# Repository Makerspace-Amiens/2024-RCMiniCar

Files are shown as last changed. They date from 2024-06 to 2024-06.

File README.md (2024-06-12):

---
layout: home
nav_order: 1
title: Accueil
---

# Bienvenue sur notre documentation du projet Voiture RC

Bienvenue dans la documentation du projet Voiture RC. Ce site a pour but de fournir toutes les informations nécessaires pour comprendre, utiliser et reproduire efficacement notre projet.

 Image Voiture RC

## À propos du Projet

<!--Décrivez ici en quelques lignes l'objectif et l'aperçu général de votre projet. Quel est son but ? À qui est-il destiné ? Quels problèmes cherche-t-il à résoudre ?-->

Le projet vise à concevoir une voiture radio télécommandée ainsi que son guide de production. L'objectif principal est de fournir aux étudiants de l'école un moyen accessible et ludique de comprendre les principes de base de l'ingénierie mécanique, électrique et de la télécommande sans fil. La conception compacte de la voiture permettra la création de circuits à taille humaine, favorisant ainsi des compétitions amusantes et éducatives entre les étudiants.

Ce projet résout plusieurs problèmes potentiels : il offre une opportunité d'apprentissage pratique, encourage la créativité et l'innovation. De plus, il permet de rendre l'apprentissage de concepts techniques plus attrayant en le contextualisant dans un cadre de jeu interactif. En fournissant un guide de production détaillé, le projet facilite également la réplication du processus de fabrication, permettant ainsi à un plus grand nombre d'étudiants de bénéficier de cette expérience enrichissante.

## Poster



## Vidéo

<video src="main/docs/images/videopres.mp4" controls title="Title" style="width: 100%;"></video>

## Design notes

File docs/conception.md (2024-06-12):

---
layout: default
nav_order: 7
title: Conception et prototypage
---

# Conception et prototypage
**Chassîs** 

Nous avons tout d’abord élaboré un plan sur papier pour estimer approximativement les tailles de nos composants ainsi que leurs emplacements. Après avoir eu une idée générale de la forme et des dimensions de notre châssis, Jules s'est chargé de le réaliser en 3D. Dans un premier temps, il a conçu un châssis très simple afin de tester les composants, commencer le câblage, le codage et vérifier le fonctionnement de la crémaillère.

Ensuite, nous avons développé un châssis plus opérationnel, avec des emplacements spécifiques pour chaque composant et des moyens de fixation adaptés. Pour ce faire, nous avons réalisé un assemblage sur SolidWorks, incluant tous les composants modélisés en 3D, afin d'obtenir les dimensions exactes de chaque élément. Cette étape nous a permis d’assurer une précision optimale dans la disposition et la fixation de chaque composant.

<script type="module" src="https://unpkg.com/@google/model-viewer/dist/model-viewer.min.js"></script>

<model-viewer id="viewer" alt="Modèle 3D du châssis" src="images/chassis3d.gltf" poster="images/Capture2.PNG" shadow-intensity="1" camera-controls touch-action="pan-y" style="width: 100%; height: 500px;">
</model-viewer>

**Crémaillère**
  
En ce qui concerne la crémaillère, nous avons d'abord effectué des recherches approfondies sur Internet pour comprendre les différents types de crémaillères utilisées dans les voitures réelles, le modélisme et les voitures radiocommandées. Ces informations nous ont permis de concevoir notre propre crémaillère sur SolidWorks.

Après avoir finalisé la conception, nous avons procédé à l'impression 3D de la crémaillère. Cependant, après plusieurs tentatives d'impression infructueuses, nous avons opté pour une impression en résine, beaucoup plus précise pour les petites pièces comme la nôtre. Cette technique nous a permis d'obtenir une crémaillère de haute qualité et adaptée à nos besoins spécifiques.

<model-viewer id="viewer" alt="Modèle 3D de la crémaillère" src="images/AssemblageCremaillere.gltf" poster="/docs/images/capture.jpg" shadow-intensity="1" camera-controls touch-action="pan-y" style="width: 100%; height: 500px;">
</model-viewer>

**Composants/Connectique**

Nous avons choisi divers composants pour réaliser cette voiture RC. Tout d'abord, nous avons fait des recherches pour déterminer quels moteurs étaient les plus propices à notre projet. Finalement, nous avons décidé de prendre des motoréducteurs moins encombrants et moins puissants. Ensuite, nous avons pris un ESP32 pour faire la relation entre les composants et nous permettre de le coder et de le contrôler soit par WiFi ou Bluetooth. D'autre part, pour faire la relation entre l'ESP32 et les motoréducteurs, nous avons pris un driver LN298 qui permet de contrôler les deux moteurs continus. Il peut faire tourner les moteurs à une vitesse continue ou en PWM. De plus, il inclut des diodes pour protéger le circuit, des résistances de rappel et un dissipateur de chaleur en cas de forte charge. Enfin, pour la direction de la voiture, nous avons pris un servo-moteur qui contribue à faire glisser la crémaillère de droite vers la gauche.
Pour la connectivité, nous avons utilisé des fils mâle/femelle et femelle/femelle pour connecter les différents composants entre eux. Cela assure une connexion fiable et flexible pour tous les éléments de la voiture RC.

<div style="display: flex; flex-wrap: wrap; gap: 10px; justify-content: space-between;">
  <model-viewer id="viewer1" alt="Modèle 3D des moteurs" src="images/moteur RC.gltf" poster="images/capture.jpg" shadow-intensity="1" camera-controls touch-action="pan-y" style="width: 22%; height: 200px;"></model-viewer>
  <model-viewer id="viewer2" alt="Modèle 3D du driver" src="images/Driver.gltf" poster="images/capture.jpg" shadow-intensity="1" camera-controls touch-action="pan-y" style="width: 22%; height: 200px;"></model-viewer>
  <model-viewer id="viewer3" alt="Modèle 3D de l'ESP32" src="images/ESP32.gltf" poster="images/capture.jpg" shadow-intensity="1" camera-controls touch-action="pan-y" style="width: 22%; height: 200px;"></model-viewer>
  <model-viewer id="viewer4" alt="Modèle 3D du servomoteur" src="images/Servo.gltf" poster="images/capture.jpg" shadow-intensity="1" camera-controls touch-action="pan-y" style="width: 22%; height: 200px;"></model-viewer>
</div>

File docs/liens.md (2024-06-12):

---
layout: default
title: Pièces STL
parent: Notice de Construction
nav_order: 2
---

# Liens des pièces

## Châssis

 - [Châssis](download/Chassis.STL)

## Composants

- [Driver](download/Driver.STL)
- [ESP32](download/ESP32.STL)
- [Moteur](download/moteurRC.STL)
- [Servomoteur](download/Servo.STL)

## Crémaillère

- [Axe droit Crémaillère](download/axedroit.STL)
- [Axe gauche Crémaillère](download/axegauche.STL)
- [Coude Crémaillère](download/coude.STL)
- [Engrenage Crémaillère](download/engrenage.STL)
- [Rampe crantée Crémaillère](download/Rampeengrenage.STL)

## Glissière

- [Glissière fixe](download/glissierefixe.STL)
- [Rail Glissière](download/railglissiere.STL)

## Roue

- [Roue arrière](download/rouearriere.STL)
- [Roue avant](download/roueavant.STL)
- [Pneu](download/contourroue.STL)

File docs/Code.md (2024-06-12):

---
layout: default
title: Code
parent: Notice de Construction
nav_order: 1
---

```
#include <DabbleESP32.h>
#include <ESP32Servo.h>

Servo myServo;

// Définir les broches de l'ESP32 connectées au module L298N
#define ENA 21  // Broche pour le PWM du moteur A
#define IN1 4  // Broche pour la direction du moteur A
#define IN2 5 // Broche pour la direction du moteur A
#define ENB 23  // Broche pour le PWM du moteur B
#define IN3 12  // Broche pour la direction du moteur B
#define IN4 13  // Broche pour la direction du moteur B

const int servoPin = 32;

// Angles pour le contrôle du servo
const int angleCentre = 133;  // Position centrale (neutre)
const int angleDroite = 180; 
const int angleGauche = 90;  
void setup() {
  // Initialiser les broches comme sorties
  pinMode(ENA, OUTPUT);
  pinMode(IN1, OUTPUT);
  pinMode(IN2, OUTPUT);
  pinMode(ENB, OUTPUT);
  pinMode(IN3, OUTPUT);
  pinMode(IN4, OUTPUT);
  
  // Initialiser la communication série pour le débogage
  Serial.begin(115200);
  myServo.attach(servoPin);
  
  // Mettre le servo en position neutre
  myServo.write(angleCentre);
  // Initialiser Dabble
  Dabble.begin("Nom_Bluetooth");  
  }

void loop() {

  Dabble.processInput();

  if (GamePad.isUpPressed()) {
    avancer();
  } else if (GamePad.isDownPressed()) {
    reculer();

  } else {
    arreter();
  }
  if (GamePad.isTrianglePressed()) {
    tournerDroite();
  } 
  
  // Vérifier si le bouton Y est pressé
  if (GamePad.isCirclePressed()	) {
    tournerGauche();
  }
  
  // Vérifier si aucun bouton n'est pressé
  if (!GamePad.isTrianglePressed() && !GamePad.isCirclePressed()) {
    arreterservo();
  }
}

void avancer() {
  // Avancer le moteur A
  digitalWrite(IN1, HIGH);
  digitalWrite(IN2, LOW);
  analogWrite(ENA, 155);  // Vitesse maximale pour le moteur A

  // Avancer le moteur B
  digitalWrite(IN3, HIGH);
  digitalWrite(IN4, LOW);
  analogWrite(ENB, 155);  // Vitesse maximale pour le moteur B

  Serial.println("Les moteurs avancent.");
}

void reculer() {
  // Reculer le moteur A
  digitalWrite(IN1, LOW);
  digitalWrite(IN2, HIGH);
  analogWrite(ENA, 155);  // Vitesse maximale pour le moteur A

  // Reculer le moteur B
  digitalWrite(IN3, LOW);
  digitalWrite(IN4, HIGH);
  analogWrite(ENB, 155);  // Vitesse maximale pour le moteur B

  Serial.println("Les moteurs reculent.");
}
void arreter() {
  // Arrêter le moteur A
  digitalWrite(IN1, LOW);
  digitalWrite(IN2, LOW);
  analogWrite(ENA, 0);  // Arrêter le moteur A

  // Arrêter le moteur B
  digitalWrite(IN3, LOW);
  digitalWrite(IN4, LOW);
  analogWrite(ENB, 0);  // Arrêter le moteur B

  Serial.println("Les moteurs sont arrêtés.");
}
void tournerDroite() {
  myServo.write(angleDroite);
  Serial.println("Tourner à droite");
}

// Fonction pour tourner à gauche
void tournerGauche() {
  myServo.write(angleGauche);
  Serial.println("Tourner à gauche");
}

// Fonction pour arrêter le servo (revenir au centre)
void arreterservo() {
  myServo.write(angleCentre);
  Serial.println("Arrêté (centre)");
}

```

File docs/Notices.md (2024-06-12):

---
layout: default
nav_order: 8
title: Notice de Construction 
has_children: true
---

# Notice de Construction de la Voiture RC

## 1. Préparation des Matériaux

### Matériaux nécessaires
Pour la réalisation de cette voiture RC, il vous faudra impérativement :

- Une imprimante 3D
- Des bobines de PLA et de TPU pour imprimer les pièces nécessaires
- Tournevis
- Fil de fer
- Rondelles
- Roulements
- Boulons
- Colle forte

## 2. Conception et Prototypage

#### Impression du châssis
La première étape consiste à imprimer le châssis qui permettra de poser et fixer les différents éléments de la voiture.

chassis

#### Impression de la crémaillère de direction
La deuxième étape consiste à imprimer les différents éléments de la crémaillère de direction.

- Une rampe crantée
- Un engrenage
- Deux coudes
- Deux axes de direction

Vous pouvez modifier les diamètres inttérieurs des des axes en fonction du diamètre exterieur de vos roulements.

<p align="center">
  rampe cr
  coude
  axe
  engrenage
</p>

#### Impression des roues
Pour finir, vous pouvez imprimer les roues, composées de deux parties : la jante en PLA et le pneu en TPU.

- Deux jantes pour l'arrière (pour les axes des moteurs)
- Deux jantes pour l'avant (pour les roulements de la crémaillère)

roue

## 3. Assemblage du Châssis et de la Crémaillère

### Assemblage de la crémaillère
1. Fixez les différents éléments de la crémaillère entre eux à l'aide de fil de fer.
2. Collez la rampe crantée au centre de la glissière (achetée ou imprimée).
3. Fixez la glissière sur le châssis à l'aide de boulons.
4. Fixez vos deux roulements sur les axes de la crémaillère.
5. Mettez les roues sur les roulements.

cremaillere

## 3. Placement des composants sur le Châssis 

### Montage des motoréducteurs
1. Placez les moteurs DC dans les supports prévus à cet effet sur le châssis.
2. Fixez les moteurs solidement pour éviter qu'ils ne bougent pendant le fonctionnement.

### Installation du module ESP32
1. Montez le module ESP32 sur le châssis.

### Installation du module L298N
1. Montez le module L298N sur le châssis.

### Installation du servo-moteur
1. Placez le servo-moteur sur son support créé sur le châssis.
2. Fixez l'écrou sur le palonnier et installez l'écrou sur la denture de la crémaillère.

voiture

## 5. Connectique entre les Composants

### Connexion du module L298N aux moteurs
Connectez les bornes de sortie du module L298N aux bornes des moteurs DC (OUT1 et OUT2 pour un moteur, OUT3 et OUT4 pour l'autre).

### Connexion du module ESP32 au module L298N
Connectez les pins IN1, IN2, IN3 et IN4 du module L298N aux GPIOs appropriés de l'ESP32.
Connectez les pins ENA et ENB du module L298N aux GPIOs de l'ESP32 pour contrôler la vitesse des moteurs.

### Connexion du servo-moteur
Connectez le servo-moteur à un autre GPIO de l'ESP32.
Connectez le fil de signal du servo au GPIO choisi, et les fils d'alimentation et de masse aux pins 3V3 et GND de l'ESP32.

### Alimentation
Connectez une source d'alimentation appropriée au module L298N pour alimenter les moteurs (Vs=7,5V).
Assurez-vous que l'ESP32 est alimenté correctement via le module L298N sur l'entrée (Vss=5V).

cablage

## 6. Programmation de l'ESP32 avec Dabble

### Programmation de l'ESP32
1. Téléchargez et installez l'IDE Arduino.
2. Installez les bibliothèques nécessaires pour l'ESP32 et Dabble.

### Téléversement du code
1. Connectez l'ESP32 à votre ordinateur via un câble USB.
2. Sélectionnez le bon port COM dans l'IDE Arduino et téléversez le code.

### Installation de Dabble
1. Téléchargez l'application Dabble sur votre smartphone depuis le Google Play Store ou l'App Store.
2. Suivez les instructions pour installer et configurer l'application.

## 7. Test et calibration
1. Allumez la voiture RC et ouvrez l'application Dabble.
2. Testez les contrôles pour vous assurer que les moteurs et le servo fonctionnent correctement.
3. Ajustez le code si nécessaire pour améliorer la réactivité et la précision des contrôles.

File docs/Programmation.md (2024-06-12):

---
layout: default
nav_order: 9
title: Programmation
has_children: true
---
# Programmation

 Pour la programmation, nous avons choisi de piloter la voiture RC sur notre smartphone, soit par WiFi, soit par Bluetooth. Nous avons fait des recherches poussées sur Internet et avons décidé d'utiliser l'interface Blynk pour le WiFi et l'interface Dabble pour le Bluetooth. Nous avons codé sur Arduino le code pour chaque interface, puis nous l'avons téléversé dans l'ESP32. Ainsi, nous pouvons contrôler l'ESP32 soit par WiFi avec Blynk, soit par Bluetooth avec Dabble sur notre smartphone.

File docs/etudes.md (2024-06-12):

---
layout: default
nav_order: 4
title: Études et choix techniques
---

# Études et choix techniques

## 1. Étude de différentes voitures RC

Nous avons étudié différents types de voitures RC DIY pour déterminer les caractéristiques souhaitées telles que la taille, le type (tout-terrain, course, drift, etc.), et la gamme de prix.

## 2. Conception et spécifications

La conception de la voiture RC est définie, incluant :

- **Châssis** : Forme, fonctionnalité, capacité a accueillir les differents composants.
- **Crémaillère** : Design, fonctionnalité.
- **Roue** : Fonctionnalité et capacité a se fixer sur les roulements et les axes des moteurs
- **Dimensions et échelle** : Nous avons choisi une longueur de 20 cm et une largeur de 10 cm en fonction de l'usage.
- **Matériaux** : Sélection des matériaux pour le châssis, batterie, moteur, driver, ESP32, servo-moteur, etc.

## 3. Système de propulsion

Le choix du système de propulsion comprend :

- **Moteurs électriques** : Plus courants, offrant différentes gammes de puissance et de performance.
- **Moteurs thermiques** : Pour les modèles plus spécialisés, offrant une expérience plus authentique mais requérant plus d'entretien.

Finalement, nous avons choisi deux motoréducteurs de 3V chacun avec une vitesse de rotation de 500 RPM, correspondant à notre couple et à une puissance suffisante pour atteindre 1,5 m/s.

## 4. Électronique et contrôle

L'électronique embarquée joue un rôle crucial dans la performance et les fonctionnalités de la voiture :

- **Récepteur et émetteur (carte ESP32)** : Pour la communication entre la voiture et la télécommande.
- **Servomoteurs** : Pour la direction de la voiture.
- **Driver L298n** : Pour faire la liasion entre l'ESP32 et les moteurs

## 5. Pneus et roues

Les pneus et les roues sont adaptés au type de surface (asphalte, terre, herbe), influençant fortement l'adhérence et la maniabilité. Nous avons choisi de concevoir nos propres roues 3D avec une adhérence conséquente pour une meilleure maniabilité.

## 6. Programmation

Le codage sur Arduino permet d'établir toutes les fonctions de paramétrage dans l'ESP32 et de contrôler notre voiture soit par WiFi, soit par Bluetooth, à partir de notre téléphone.

## 7. Prototypage et tests

La fabrication du prototype sera suivie de tests nécessaires pour valider la conception, la durabilité et les performances. Cela peut inclure des ajustements et des modifications durant le projet.

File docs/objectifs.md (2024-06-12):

---
layout: default
nav_order: 3
title: Objectifs du projet
---

# Introduction

L'innovation et la technologie continuent de s'améliorer, et nous allons vous présenter nos objectifs pour la réalisation d'une voiture télécommandée conçue de A à Z. Ce projet incarne des mois de recherche, de conception et de tests, motivés par une passion pour l'ingénierie et une volonté de réussir.

Dans les paragraphes suivants, nous allons détailler le contexte, les objectifs et le cahier des charges du projet.

## Contexte du Projet

Étant étudiants en 3ème année d'école d'ingénieur, nous devons réaliser un projet de 75 heures. Passionnés d'automobile, nous avons choisi le projet de création d'une voiture RC. Au cours de notre cursus, nous avons appris la mécanique, l'électronique et la programmation théorique. Ce projet réunit ces trois disciplines et nous donnera l'occasion de renforcer notre compréhension des principes mécaniques (transmissions, suspensions), nos pratiques dans les circuits électriques et les systèmes de contrôle, ainsi que nos compétences en programmation.

En plus de servir d'apprentissage, ce projet offrira également une expérience pratique de travail en équipe. Chaque membre apportera ses connaissances en modélisation 3D, électronique et programmation. Ensemble, nous concevrons une voiture RC fonctionnelle.

Ainsi, le projet de création d'une voiture RC représente une opportunité passionnante dans notre cursus d'ingénieur et nous permettra de renforcer nos compétences techniques et notre capacité à collaborer.

## Objectifs du Projet

- Apprentissage de la mécanique, de l'électronique et de la programmation d'une voiture RC.
- Conception 3D de la voiture RC.
- Choix des bons composants (batteries, moteur, suspension, etc.).
- Création d'une carte électronique entre le moteur et la carte ESP32.
- Avoir une voiture fonctionnelle.
- Piloter la voiture avec notre téléphone en Bluetooth.

## Cahier des Charges

-Concevoir une voiture RC fonctionnelle

-Petite/moyenne taille (+-Longueur de 20cm, largeur de 10cm)

-Choisir des composants adaptés aux attentes de la voiture :

-Petite/moyenne

-Légère

-Vitesse de 5 km/h

-Contrôlable à distance

-intégrer les composants au châssis

-piloter la voiture avec son smartphone

-Budget de 150 € pour le développement complet du projet

### 3. Spécifications Techniques

- **Conception et Dimensions :** Longueur de 20 cm, largeur de 10 cm, châssis en 3D.
- **Système de Propulsion :** 2 motoréducteurs de 3V, 500 RPM, vitesse de 1,5 m/s.
- **Contrôle et Communication :** Carte ESP32, application mobile via Bluetooth ou WiFi pour les réglages avancés sur smartphone. Utilisation d'un driver LN298.
- **Alimentation :** Batterie LiPo 7.4V 5000mAh, autonomie de 30 minutes, recharge rapide en 1 heure.
- **Direction :** Direction assistée électroniquement par un servo-moteur fesant bouger une crémaillère.

### 4. Critères de Conception

- **Personnalisation :** 
  - Création d'un châssis s'adaptant à tous les composants utilisés.
  - Élaboration d'une coque de protection de la voiture RC.
  - Programmation de l'ESP32 à partir d'Arduino pour contrôler la voiture via un téléphone.

### 5. Plan de Développement

- **Phases du Projet :** Conception, Développement du prototype, Tests.
- **Calendrier :** Début du projet en février 2024, fin en juin 2024.
- **Ressources :** Équipe de 3 étudiants ingénieurs, logiciels de CAO, internet, etc.
- **Budget :** Estimé à 150 € pour le développement complet du projet.

### 6. Tests et Validation

- **Protocole de Tests :** Tests de performance, tests de résistance (chocs, usure), tests d'usage (contrôle, programme).
- **Critères de Validation :** Obtenir une voiture fonctionnelle et pilotable.

### 7. Modifications

- **Rapport de Projet :** Analyse des performances, retour sur le projet, améliorations, défauts.

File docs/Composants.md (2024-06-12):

---
layout: default
nav_order: 6
title: Les Composants
---

# Composants

## Module L298N
<div style="text-align: center;">
  Module L298N
</div>
<div style="text-align: left;">
  Le module L298N est un pont en H double qui permet de contrôler deux moteurs à courant continu ou un moteur pas à pas.

  Les Caractéristiques Techniques du Module L298N sont: Au niveau de l'Alimentation, Nous avons une Tension d'alimentation (Vss) de 5V, une Tension d'alimentation du moteur (Vs) : 5V à 35V
  un Courant de sortie maximal par canal : 2A

  Pour le Contrôle des Moteurs, il y a deux canaux : 2 (peut contrôler 2 moteurs DC ou 1 moteur pas à pas)
  avec une Puissance de sortie totale : 25W

  Les Connexions et les Broches :
  Les Broches IN1, IN2, IN3, IN4 : Entrées de contrôle pour les deux moteurs
  Les Broches ENA, ENB : Broches d'activation pour les moteurs A et B (permettent le contrôle de la vitesse avec PWM)
  Les Broches OUT1, OUT2, OUT3, OUT4 : Sorties vers les moteurs
  Les Broches Vss et GND : Connexion à l'alimentation logique
  La Broche Vs : Connexion à l'alimentation des moteurs

  Les Fonctionnalités
  Il est capable de contrôler la direction et la vitesse de rotation des moteurs.
  Il permet d'utiliser des signaux PWM pour contrôler la vitesse des moteurs.
  Il peut être utilisé pour contrôler des moteurs à courant continu, des moteurs pas à pas bipolaires ou unipolaires.
</div>

## ESP32
<div style="text-align: center;">
  ESP32
</div>
<div style="text-align: left;">
  L'ESP32 est une série de microcontrôleurs. Nous l'avons choisi en raison de ses caractéristiques avancées et de sa polyvalence.

  Les Caractéristiques Principales

  Une Connectivité Sans Fil :

  Avec le Wi-Fi, il permet la connexion à des réseaux sans fil pour la communication et l'échange de données.
  Avec le Bluetooth et BLE (Bluetooth Low Energy) qui supporte les communications Bluetooth classiques et basse consommation, permettant une large gamme d'applications sans fil.

  De Nombreuses Interfaces de Communication :

  -GPIO : Plusieurs broches d'entrée/sortie générales.
  -ADC (Convertisseur Analogique-Numérique) : Permet de lire des signaux analogiques.
  -DAC (Convertisseur Numérique-Analogique) : Génère des signaux analogiques.
  -PWM (Modulation de Largeur d'Impulsion) : Contrôle de la luminosité des LEDs, moteurs, etc.
  -I2C, SPI, UART : Protocoles de communication pour interfacer divers capteurs et périphériques.

  Prototypage Rapide :

  Nous l'avons utilisé pour programmer sur Arduino IDE pour ainsi piloter notre voiture RC.

  Les avantages de l'ESP32 sont:
  La polyvalence avec une large gamme de fonctionnalités et de périphériques intégrés.
  Une connectivité Wi-Fi et Bluetooth intégrés.
  Une performance avec Processeur puissant capable de gérer des tâches complexes.

  En résumé, l'ESP32 est un microcontrôleur très polyvalent et puissant, grâce à ses capacités de connectivité sans fil et ses fonctionnalités, il nous a permis de développer notre projet.
</div>

## Motoréducteurs
<div style="text-align: center;">
  Motoréducteurs
</div>
<div style="text-align: left;">
  Un motoréducteur est un dispositif qui combine un moteur électrique avec un réducteur de vitesse. Ce composant est utilisé pour faire déplacer notre voiture RC.
  Le moteur fournit la puissance de rotation initiale.
  Ce sont des moteurs à courant continu (DC).
  Le réducteur de vitesse est constitué d'un ensemble d'engrenages qui réduisent la vitesse de rotation du moteur tout en augmentant le couple.
  Pour le Fonctionnement,
  Le moteur électrique génère une vitesse de rotation élevée mais avec un couple relativement faible. Le réducteur de vitesse, à travers son système d'engrenages, réduit cette vitesse de rotation tout en augmentant le couple. La sortie de cette combinaison est une vitesse de rotation plus basse mais avec un couple plus élevé.
</div>

## Servo moteur
<div style="text-align: center;">
  Servo moteur
</div>
<div style="text-align: left;">
  Un servo moteur est un type de moteur électrique qui est spécialement conçu pour permettre un contrôle précis de la position angulaire, de la vitesse et du couple. Notre servo moteur, nous sert pour la direction de notre voiture.
  Il est doté d'un moteur à courant continu (DC), d'un ensemble d'engrenages  permettant un contrôle plus précis des mouvements.
  Un circuit électronique intégré qui reçoit les signaux de commande de l'ESP32 et ajuste la position.

  Un potentiomètre mesure la position actuelle de l'axe du moteur.Le retour de ce capteur est utilisé pour ajuster la position en fonction de l'utilisation. Pour nous 45° pour tourner à droite et -45° pour tourner à gauche.

  Un signal de commande (généralement un signal PWM - Pulse Width Modulation) est envoyé au servo moteur.
  Ce signal détermine la position cible de l'axe du moteur.
  Le capteur de position mesure la position actuelle de l'axe et envoie cette information au circuit de contrôle.

  Le servo peut tourner sur un angle limité généralement 180 degrés ou moins.

  En résumé, un servo moteur est un dispositif essentiel pour un contrôle précis de la direction de notre voiture.
</div>

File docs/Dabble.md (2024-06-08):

---
layout: default
title: Interface Dabble
parent: Programmation
nav_order: 2
---

# Dabble

Dabble est une application mobile pour interagir avec les microcontrôleurs comme l'ESP32 en Bluetooth. 
Elle transforme un smartphone en un contrôleur polyvalent,  nous permettant de contrôler notre voiture RC. 

Une interface avec divers modules et outils pour interagir avec des projets électroniques.

Les Modules et  Les Fonctionnalités sont:

Gamepad : Permet d'utiliser le téléphone comme un contrôleur pour piloter des voitures RC.
Terminal : Interface pour envoyer et recevoir des données textuelles, permettant de déboguer ou de contrôler les appareils.
Capteurs : Utilise les capteurs intégrés du smartphone (comme l'accéléromètre, le gyroscope, etc.) pour contrôler les appareils ou collecter des données.
Commande vocale : Permet de contrôler les appareils via des commandes vocales.
Graphiques : Visualisation en temps réel des données collectées par les capteurs.
LED et Buzzer : Contrôle des LEDs et des buzzers connectés aux microcontrôleurs.

La Compatibilité :
Elle fonctionne avec divers microcontrôleurs tels que Arduino, ESP32, et autres.
Elle utilise le Bluetooth pour la communication, rendant notre projet simple et sans fil.

L'Utilisation :
Interraction entre la programmation et l'électronique de notre voiture RC.
Contrôle des commandes : Utilisé pour contrôler les moteurs et le servo moteur de notre voiture télécommandée.

Donc, Dabble transforme un smartphone en un contrôleur multi-fonctions pour interagir avec les microcontrôleurs via Bluetooth.
Une Compatibilité qui fonctionne avec Arduino, ESP32...
Nous l'avons utilisé dans notre projets d'ingénieur dans le domaine du prototypage.

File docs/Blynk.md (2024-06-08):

---
layout: default
title: Interface Blynk
parent: Programmation
nav_order: 1
---
# Blynk

Blynk est une plateforme Internet qui nous a permis de contrôler L'ESP32 à distance via l'applications mobile. 

Elle fournit une application mobile.
Elle permet de créer des interfaces personnalisées pour interagir avec les appareils connectés.
Utilise des widgets comme des boutons, des sliders pour activer les commandes

Elle est compatible avec Arduino, ESP32. Elle prend en charge différentes communication, notamment Wi-Fi, Bluetooth.

Elle est composée de trois principaux éléments : l'application mobile, le serveur Blynk, et les bibliothèques Blynk sur Arduino.
L'Application Mobile sert à  l'utilisateur d'interagir avec les appareils.
Le Serveur Blynk est un Centre de communication entre l'application et les appareils. 
La Bibliothèque Blynk Fournisse les fonctions nécessaires pour connecter les appareils au serveur Blynk et envoyer/recevoir des données.

Ainsi, 
Blynk est une interface intuitive avec desoutils de développement. Elle est compatible avec une large gamme de matériels comme l'ESP32 qui nous a permis de controler nos moteurs et le servo moteur à distance.

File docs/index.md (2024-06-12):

---
layout: home
nav_order: 1
title: Accueil
---

# Bienvenue sur notre documentation du projet Voiture RC

Bienvenue dans la documentation du projet Voiture RC. Ce site a pour but de fournir toutes les informations nécessaires pour comprendre, utiliser et reproduire efficacement notre projet.

<script type="module" src="https://unpkg.com/@google/model-viewer/dist/model-viewer.min.js"></script>

<div style="display: flex; justify-content: space-between;">
    <model-viewer id="viewer" alt="Modèle 3D Voiture RC" src="images/ASSEMBLAGE.gltf" poster="" shadow-intensity="1" camera-controls touch-action="pan-y" style="width: 49%; height: 500px;">
    </model-viewer>
    Image Voiture RC
</div>

## À propos du Projet

<!--Décrivez ici en quelques lignes l'objectif et l'aperçu général de votre projet. Quel est son but ? À qui est-il destiné ? Quels problèmes cherche-t-il à résoudre ?-->

Le projet vise à concevoir une voiture radio télécommandée ainsi que son guide de production. L'objectif principal est de fournir aux étudiants de l'école un moyen accessible et ludique de comprendre les principes de base de l'ingénierie mécanique, électrique et de la télécommande sans fil. La conception compacte de la voiture permettra la création de circuits à taille humaine, favorisant ainsi des compétitions amusantes et éducatives entre les étudiants.

Ce projet résout plusieurs problèmes potentiels : il offre une opportunité d'apprentissage pratique, encourage la créativité et l'innovation. De plus, il permet de rendre l'apprentissage de concepts techniques plus attrayant en le contextualisant dans un cadre de jeu interactif. En fournissant un guide de production détaillé, le projet facilite également la réplication du processus de fabrication, permettant ainsi à un plus grand nombre d'étudiants de bénéficier de cette expérience enrichissante.

## Poster



## Vidéo

<video src="images/videopres.mp4" controls title="Title" style="width: 100%;"></video>

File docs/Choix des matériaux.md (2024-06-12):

---
layout: default
nav_order: 5
title: Choix des matériaux 
---

# Choix des matériaux 

Comme vous le savez pour ce projet nous voulions réaliser une voiture radio télécommandée accessible à tous avec des composants électroniques simple et répandu mais aussi avec des composants conçu uniquement à l’aide du matériel présent dans le Maker Space. 
Voici un tableau des matériaux utilisable dans le Maker Space ainsi que leurs caractéristiques : 

| Matériaux | Outil à utiliser | Avantages | Inconvénients |  
|:--- |:--- |:--- |:--- |
| TPU | imprimante 3D | plastique mou / très peu onéreux / toute formes | se dissout dans l'eau |  
|  PLA | imprimante 3D | très peu onéreux / toute formes | sensible à la chaleur |  
| Résine | imprimante UV | très précis / peu onéreux | casse facilement / long à imprimer |  
| Bois | découpeur laser | très peu onéreux / très rapide | relativement limité au niveau de la forme | 

Ensuite après avoir listé tout les matériaux qui s’offraient à nous, il ne rester plus qu’à choisir selon nos besoins bien spécifiques : 

**Le châssis**   
Pour le châssis nous avions besoins d’un matériaux peu onéreux , très modulable au niveau de la forme ainsi et très solide. C’est pourquoi notre choix c’est portée sur le PLA. 

**Les roues**   
Pour les roues nous avions besoin d’un matériaux capables d’allier adhérence et absorption des chocs lorsque la voiture roule, c’est pourquoi nous avons opté pour le TPU. Or après plusieurs essais nous avons pour remarquer que nous avions besoins d’un matériaux solide pour l’intérieur de ces dernière, donc nous avons fait une jante en PLA et un pneu en TPU pour allier les avantages de ces deux matériaux tout en gommant les inconvénients de chacun. 

**la crémaillère de direction**   
Notre crémaillère est un assemblage de petite pièces composées de beaucoup de détail, c’est pourquoi nous avions besoins d’un matériaux qui pourrait être travaillé avec précision. Après plusieurs test non concluant avec une imprimante 3D et son PLA, nous avons opté pour de la résine qui offre une précision incomparable.

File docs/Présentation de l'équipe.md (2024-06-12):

---
layout: default
nav_order: 2
title: Présentation de l'équipe
---

# Présentation de l'équipe 

Nous sommes trois étudiants à UniLaSalle Amiens en première année de cycle ingénieur, tout trois passionnés d’automobiles et de robotiques, ce projet de voiture radio télécommandée est pour nous un vrai défi à relever ! 

<div class="grid-container" style="display: flex; justify-content: space-around;">
    <div style="text-align: center;">
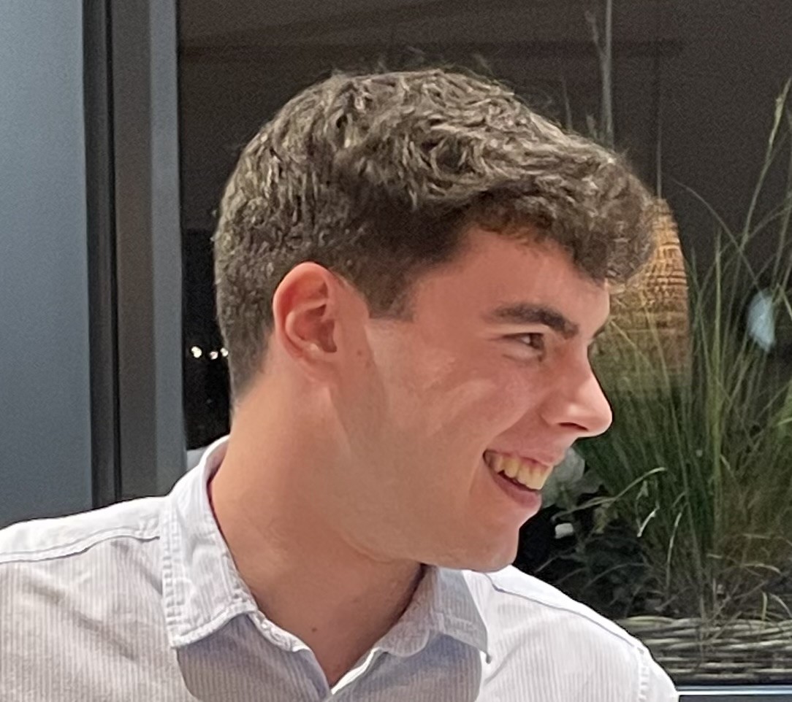
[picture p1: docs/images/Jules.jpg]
Photo Jules
        
        <p class="image-caption">Jules Mailly</p>
    </div>
    <div style="text-align: center;">
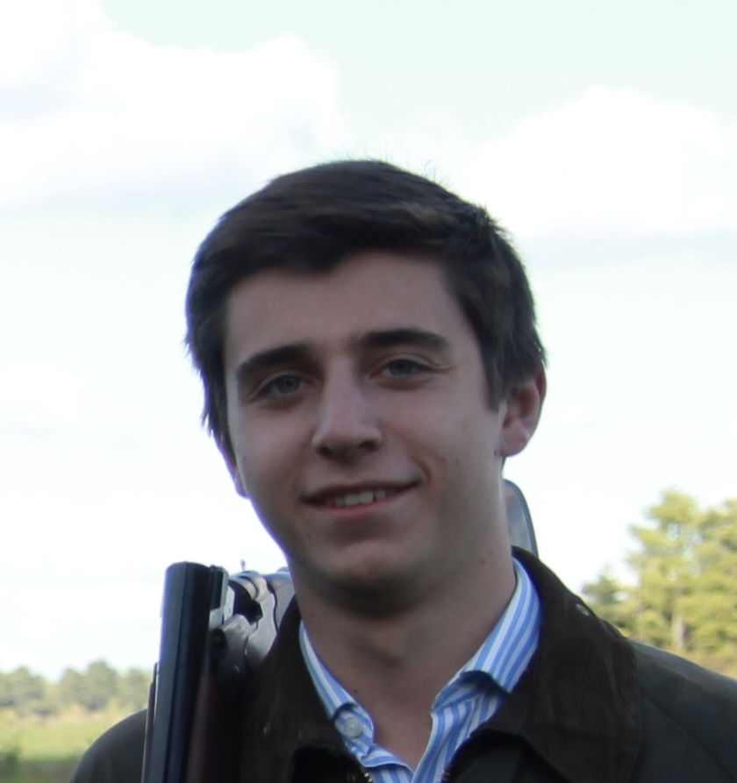
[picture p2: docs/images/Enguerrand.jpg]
Photo Enguerrand
        
        <p class="image-caption">Enguerrand CUIF</p>
    </div>
    <div style="text-align: center;">
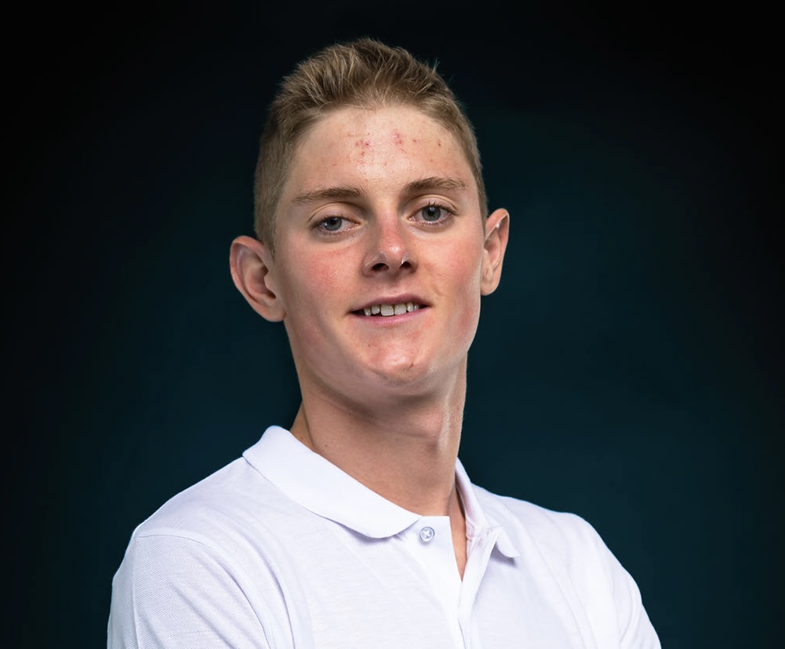
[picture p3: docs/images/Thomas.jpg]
Photo Thomas
        
        <p class="image-caption">Thomas LE PAPE</p>
    </div>
</div>

<div class="table-wrapper">
    <table>
        <thead>
            <tr>
                <th style="text-align: center">&nbsp;</th>
                <th style="text-align: center">Programmation</th>
                <th style="text-align: center">Bricolage</th>
                <th style="text-align: center">Modélisation</th>
                <th style="text-align: center">Conception</th>
            </tr>
        </thead>
        <tbody>
            <tr>
                <td style="text-align: center">Jules MAILLY</td>
                <td style="text-align: center">3</td>
                <td style="text-align: center">4</td>
                <td style="text-align: center">5</td>
                <td style="text-align: center">4</td>
            </tr>
            <tr>
                <td style="text-align: center">Enguerrand CUIF</td>
                <td style="text-align: center">3</td>
                <td style="text-align: center">5</td>
                <td style="text-align: center">4</td>
                <td style="text-align: center">4</td>
            </tr>
            <tr>
                <td style="text-align: center">Thomas LE PAPE</td>
                <td style="text-align: center">5</td>
                <td style="text-align: center">4</td>
                <td style="text-align: center">3</td>
                <td style="text-align: center">4</td>
            </tr>
        </tbody>
    </table>
</div>

**répartition des tâches**

*Thomas Le Pape* : réalisation du programme pour radio télécommandée la voiture 

*Jules Mailly* : réalisation de la modélisation 3D du châssis de la voiture 

*Enguerrand Cuif* : réalisation de la crémaillère de direction de la voiture

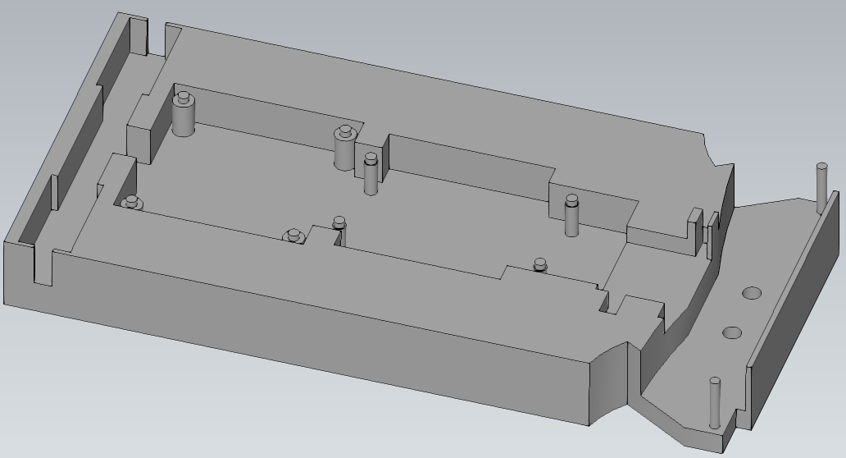
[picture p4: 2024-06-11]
docs/images/Capture2.PNG

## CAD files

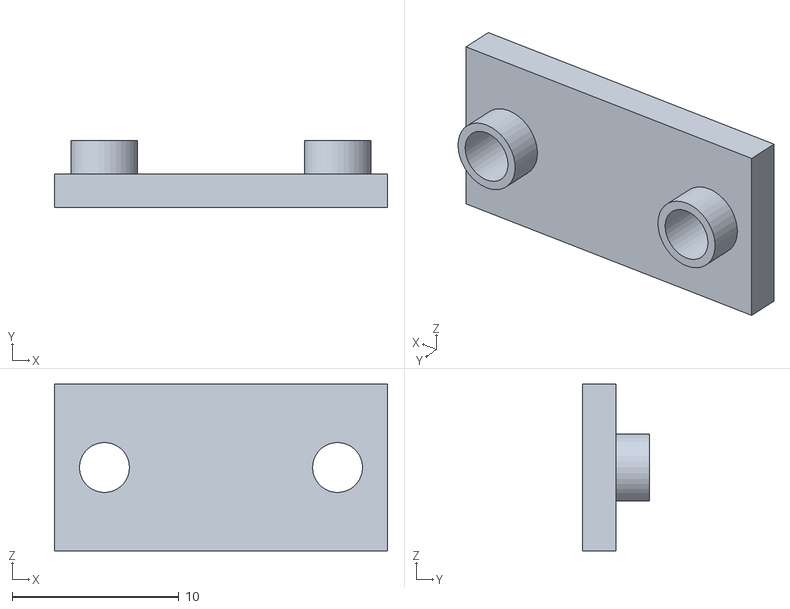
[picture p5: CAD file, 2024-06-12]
docs/download/glissierefixe.STL
20.0 x 4.00 x 10.0

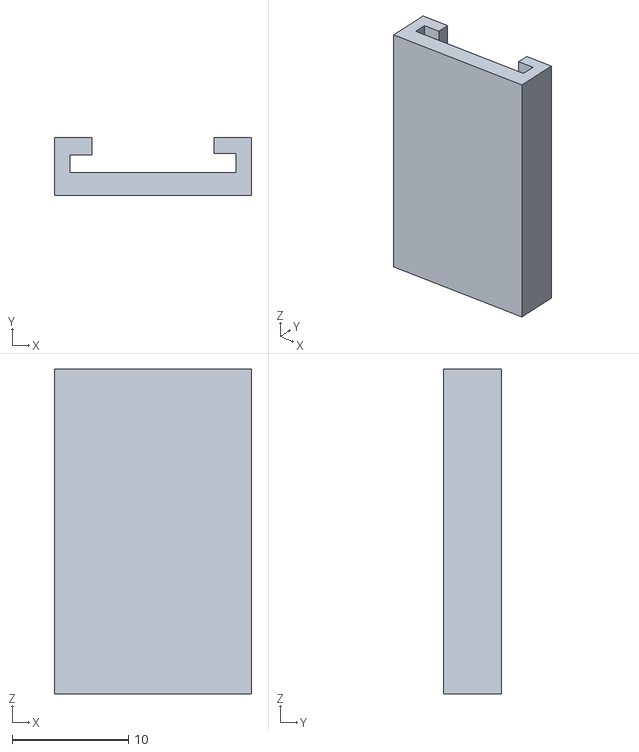
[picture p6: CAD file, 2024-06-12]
docs/download/railgilssiere.STL
17.0 x 5.00 x 28.0

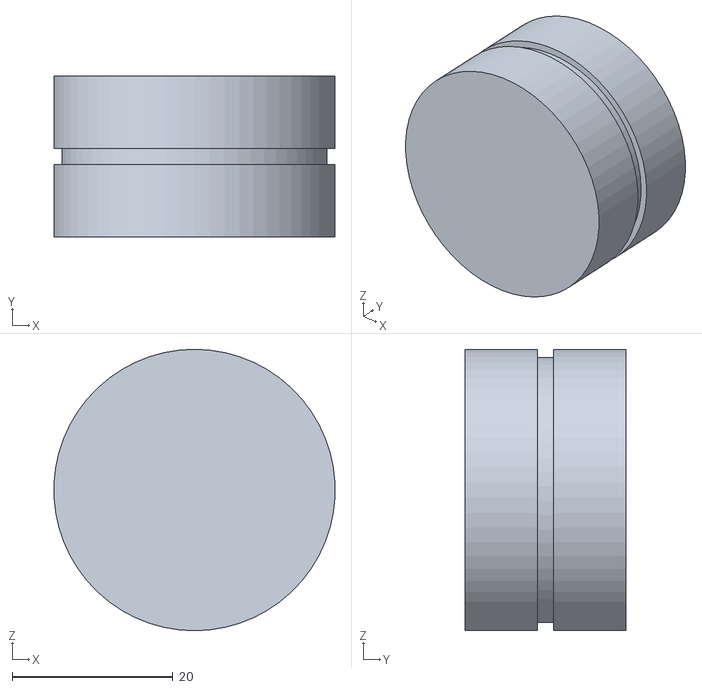
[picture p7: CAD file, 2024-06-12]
docs/download/rouearriere.STL
34.9 x 20.0 x 35.0

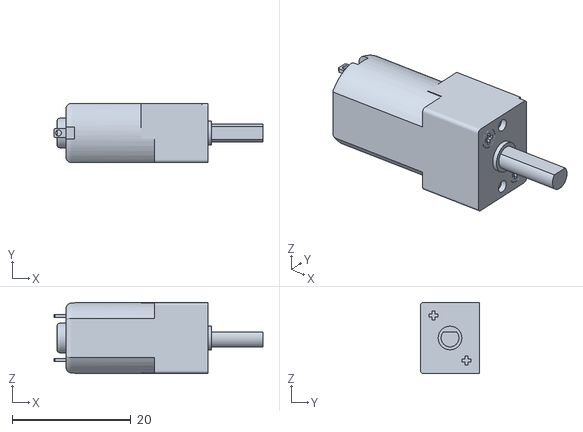
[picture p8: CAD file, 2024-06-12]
docs/download/moteurRC.STL
35.3 x 10.00 x 12.0

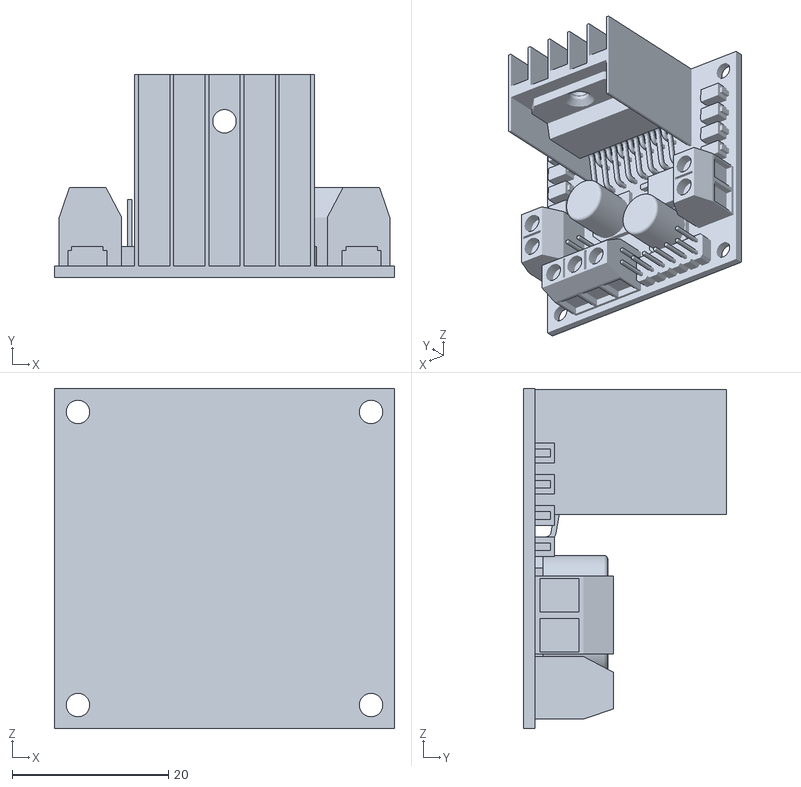
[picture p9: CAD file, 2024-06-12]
docs/download/Driver.STL
43.5 x 26.0 x 43.5

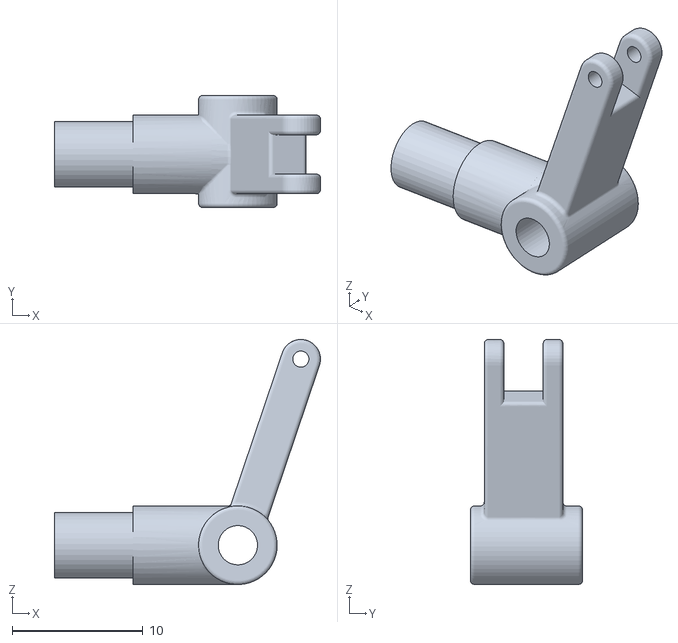
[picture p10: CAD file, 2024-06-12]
docs/download/axedroit.STL
20.3 x 8.55 x 18.7

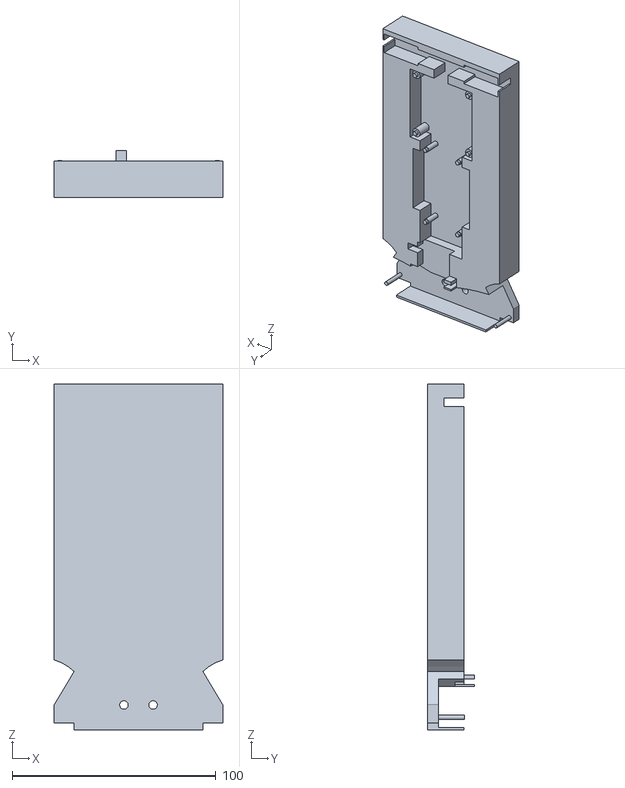
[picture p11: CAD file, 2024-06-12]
docs/download/Chassis.STL
82.8 x 23.0 x 170.0

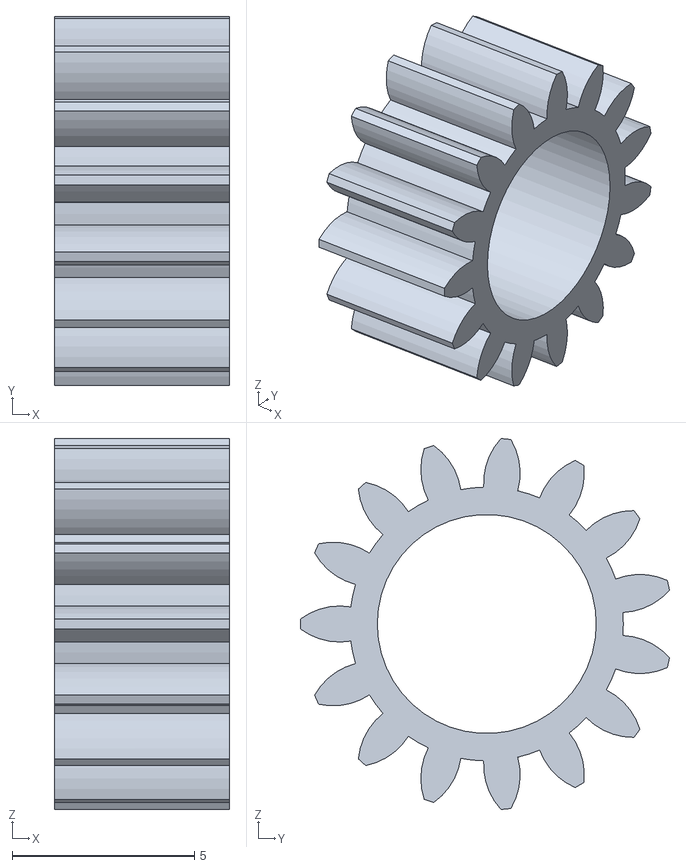
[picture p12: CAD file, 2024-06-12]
docs/download/engrenage.STL
4.80 x 10.1 x 10.2

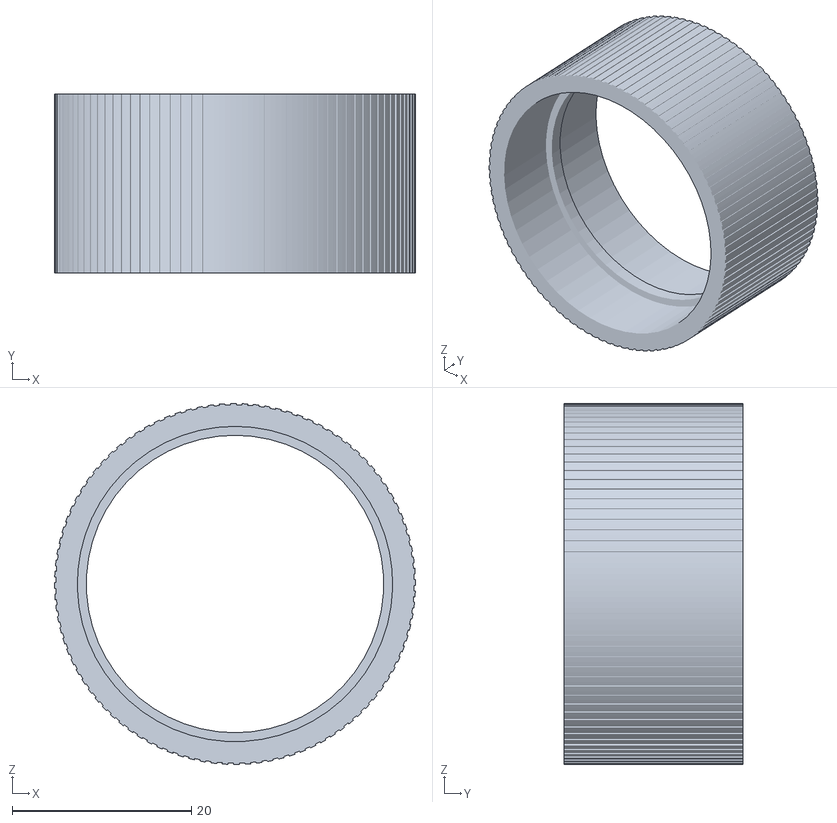
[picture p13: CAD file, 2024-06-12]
docs/download/contourroue.STL
40.3 x 20.0 x 40.3

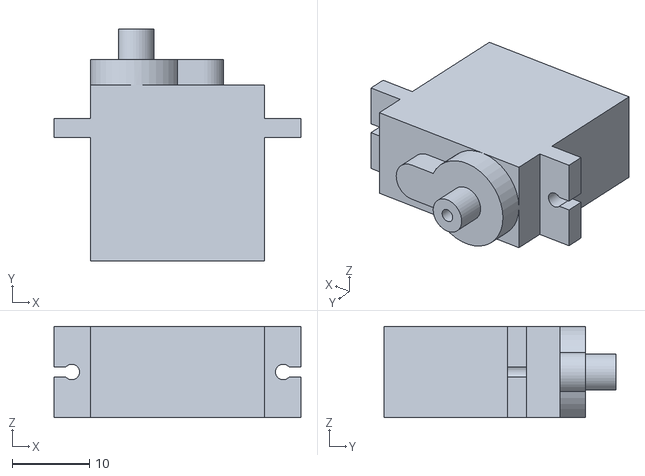
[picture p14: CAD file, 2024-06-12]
docs/download/Servo.STL
31.9 x 29.9 x 11.8

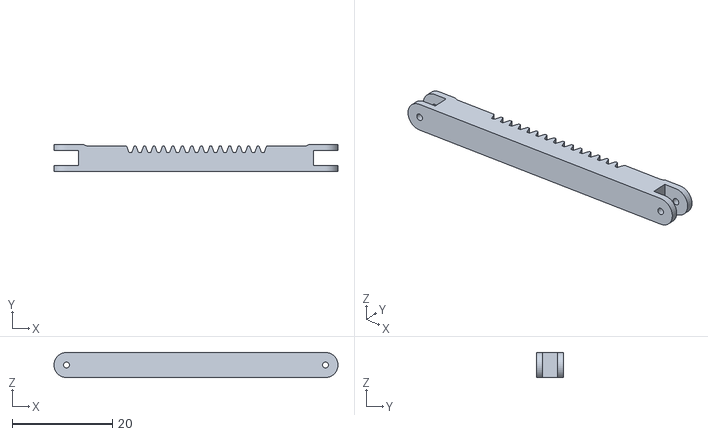
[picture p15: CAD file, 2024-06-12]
docs/download/Rampeengrenage.STL
56.6 x 5.40 x 5.00

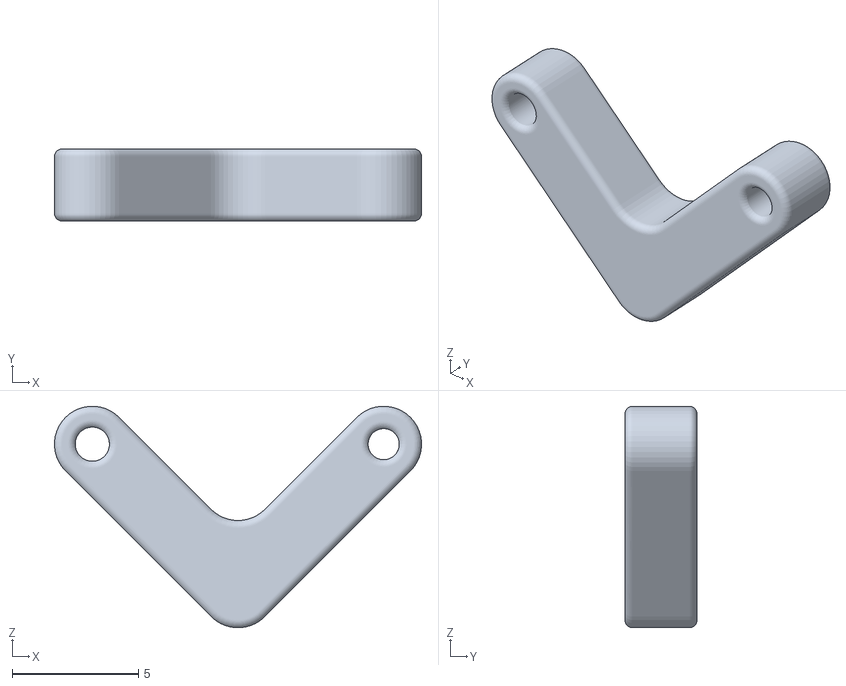
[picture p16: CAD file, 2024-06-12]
docs/download/coude.STL
14.5 x 2.85 x 8.76

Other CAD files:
docs/download/roueavant.STL
docs/download/axegauche.STL

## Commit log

2024-06-06 Create Présentation de l'équipe
2024-06-06 Create Présentation de l'équipe.md
2024-06-06 Update Présentation de l'équipe.md
2024-06-07 Update Choix des matériaux.md
